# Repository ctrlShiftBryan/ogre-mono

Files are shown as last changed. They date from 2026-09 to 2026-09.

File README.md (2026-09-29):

# Ogre 68

A 68-key ergonomic keyboard, written by hand for
[ergogen](https://ergogen.xyz): key layout, board outline and a KiCad PCB, all
generated from one `ergogen/config.yaml`. It is a wireless split: one PCB per
half, each with its own nRF52840 module and power section on the board, laid
out for JLCPCB assembly.

34 keys a half: four staggered rows, a three-key inner column, a lone Esc
outboard of the number row, two arrow keys, and a four-key thumb cluster fanned
30°. Standard keycap sizes throughout — 1U alphas, 1.5U/1.75U/1.25U on the outer
column, 1.25U and 2.25U thumbs. `ergogen/README.md` describes the design;
`ergogen/ogre-ergo.keycaps.svg` renders it.

## Where it stands

- Layout, outline and PCBs all generate from the config: 68 keys on a 5x7
  matrix per half laid out for routing (the physical columns and rows, with
  the thumbs, arrows and Esc / Del fitted in), hotswap sockets
  with one diode per key, and an Ebyte E73 nRF52840 module with the nice!nano
  v2's power section on each half, all surface mount from JLC's parts library.
- The design's own values — column staggers, thumb fan, half separation — are
  named in the config's `units` block, so the board is tuned in one place.
- `npm run snapshot` holds the geometry against a committed baseline, so a key
  that moves without you meaning it fails.
- `npm run check` passes: wiring, every controller and power pin on its net,
  and KiCad DRC with no violations beyond the unrouted connections.
- **Next:** routing: a routed board as the copper master, with the build syncing
  placement into it. Mounting holes wait on the case.

## Working on it

```sh
cd ergogen && npm install
npm run serve     # live viewer on http://localhost:5174
```

The viewer watches `config.yaml` and `footprints/`, rebuilds on save and
refreshes itself: keycaps, points, outlines and the PCB, with the snapshot and
check scripts a button away. `ergogen/README.md` covers the other commands, the
PCB's matrix and break lines, and the ZMK changes the two removed keys imply.

## The rest of the repo

| Where | What |
|---|---|
| `ergogen/` | The Ogre 68: config, custom footprints, build and check scripts, live viewer |
| `layout/` | The 2019 Ogre Ergo's KLE design, its renderer, and an index of every KLE gist |
| `docs/ogre-repos.md` | Inventory of every Ogre repo — PCBs, firmware branches, tooling — and the project timeline |

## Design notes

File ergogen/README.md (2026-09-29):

# The Ogre 68 in ergogen

`config.yaml` is the whole board, written by hand for
[ergogen](https://ergogen.xyz): key layout, board outline and an unrouted
KiCad PCB. It needs ergogen 4.1+ and the custom footprints in `footprints/`.
On ergogen.xyz (or a local clone of `ergogen/ergogen-gui`), load it from GitHub
with the repo URL (it finds `ergogen/config.yaml` and `ergogen/footprints/`
itself); pasting the YAML alone won't work, because the footprints wouldn't
load. That web UI reads the pushed repo, not the working tree, and its local
file picker is a one-shot upload that brings no footprints; for local work
use `npm run serve` below.

| File | What it is |
|---|---|
| `config.yaml` | Layout, outline and PCB |
| `footprints/` | The switch, its socket and diode, the nRF52840 module, charger, LDO, passives, crystal, connectors, switches, LEDs and SWD pads on the board (`ogre_*.js`); the 2019 PCB-mount switch, diode, Pro Micro and TRRS jack, the nice!nano and the through-hole JST PH connector, available but not placed |
| `footprints/jlc/` | Footprints pulled verbatim from JLCPCB's parts library with easyeda2kicad, one per assembled part, each carrying its LCSC number; `jlc.js` turns them into ergogen footprints |
| `serve.js` | Live viewer: watches the config, rebuilds and shows every view |
| `bundle.js` | Packs the config and footprints into an archive the web UI can open |
| `points.snapshot.json` | Baseline geometry for `npm run snapshot` |
| `ogre-ergo.keycaps.svg` | Key preview |
| `ogre-ergo.keycaps-print.svg` | The same keys for printing: white caps, black type, 1:1 in mm |

## The design

Everything that shapes the board is named in the config's `units` block. The
zones below it place keys and give them legends; the shape lives in `units`.

- **34 keys a half.** Four rows across six columns (outer, pinky, ring, middle,
  index, inner), a three-key extra column inboard of them, a lone Esc on the far
  column, two arrow keys below ring and middle, and four thumb keys.
- **Column stagger.** Each column steps against the one before it, and the
  steps add up to the profile across the hand: the middle column is highest at
  +0.375U, falling away to the pinky on one side and the inner and extra
  columns on the other. `stagger_far` through `stagger_extra`.
- **Key sizes.** 1U throughout, except the outer column's wide caps —
  1.5U Tab, 1.75U Caps Lock, 1.25U Ctrl — right-aligned to the pinky column.
- **Thumb cluster.** Three columns fanned `thumb_splay` (−30°) off the bottom
  of the middle column: 1.25U Cmd, 2.25U Shift, then 1.25U Alt with a 1U Home
  above it. The wide thumb caps are drawn as wide keys turned 90°, so switch
  and stabilizer footprints face the right way.
- **Halves.** Mirrored about an axis `half_spread` (4.25U) right of the extra
  column, which sets the gap between them.

## Legends

Each key has a `legend`: what's printed on a standard keycap set, not the
firmware keymap. `mirror.legend` is the legend of the matching key on the
right half, since ergogen builds the right half by mirroring the left. The PCB
prints each legend on both silkscreens, under its switch (readable from the
back once the switches are in).

Two-part legends are written shifted character first, then base, separated by
a space: `'! 1'` is the key with `!` over `1`. Anything else (`Esc`,
`Caps Lock`, `←`) is a single legend.

## The PCB

Two boards, always split, one per half: `left` and `right`, each its own KiCad
PCB with its own nets. Wireless only, with the controller on the board itself:
an nRF52840 module and the nice!nano v2's power section, all surface mount on
the back, for JLCPCB assembly. The matrix comes from the 2019 Ogre Ergo, where
it was fabricated and worked; the switch footprint from the 2024 rework
(`ogre.2024.pretty`); everything JLC places uses JLC's own footprint
(`footprints/jlc/`), so the pads and orientation match their line.

- **Key numbers.** Each half numbers its keys 1–34 in points order: up each
  column from the outer edge inward, then the thumbs. Key *n* on a half is that
  board's switch MX*n*, socket S*n* and diode D*n*. The keycap render
  (`ogre-ergo.keycaps.svg`, and the viewer's Keycaps tab) prints each key's
  number as L*n* or R*n*, and `npm run check` fails if a part is numbered out
  of step with its key.
- **One 10×7 matrix, one hotswap socket and one diode per key**, COL2ROW. The
  switch (`ogre_hotswap`) is holes, cap outline and legend; its copper is the
  socket (`ogre_socket`, a Kailh-compatible MX socket, JLC's clone) and the
  1N4148W diode in SOD-123F (`ogre_socket_diode`), each a part of its own on
  the back so it can be moved clear of traces. The socket places itself over
  the switch's pins; a key's `diode: [x, y, r]` in the zones places its diode
  (mm from the key, in its frame, y up; `mirror.diode` for the right half),
  and without one it sits at the switch's right edge, where the 2024 footprint
  had it built in. The 2.25U thumb keys add stabilizer holes (a key's `stab`),
  and a key's `turn` would turn its switch and socket together (no key uses it
  now). The grid is laid out for routing, five rows by seven columns:

  |          | col0 | col1 | col2 | col3 | col4 | col5  | col6 |
  |----------|------|------|------|------|------|-------|------|
  | **row0** | + =  | 1    | 2    | 3    | 4    | 5     | ~ \` |
  | **row1** | Tab  | Q    | W    | E    | R    | T     | } ]  |
  | **row2** | Caps | A    | S    | D    | F    | G     | PgDn |
  | **row3** | Ctrl | Z    | X    | C    | V    | B     | Home |
  | **row4** | Esc  |      | ←    | →    | Cmd  | Shift | Alt  |

  Each column net runs down a physical column, col0 the outer column through
  col6 the extra column, and each thumb key joins the column above it. Rows
  0–3 are the physical rows, with Home filling the extra column's empty bottom
  spot, and row4 gathers the rest: Esc, the arrows and the other thumbs. The
  right half is the same grid, mirrored (Del, End, Fn, Enter), on rows 5–9.
  Each half is its own PCB with its own nets, so the numbering across both is
  a convention, not a wire.
- **The controller** (MCU1): an Ebyte E73-2G4M08S1C, an nRF52840 module with
  its antenna, matching and crystals inside, lying sideways on the back below
  the extra column's home key (PgDn / `" '`), where that column has no bottom
  key, with its ceramic antenna end just inside the half's inner edge. Keep
  copper off that end on both layers; the diodes of the two keys beside it are
  moved out of its way in the zones. Its pin map is in `footprints/ogre_e73.js`: the seven
  columns on P1.10 P0.03 P0.28 P1.13 P0.02 P0.29 P0.31 (module pins
  2–9), the half's five rows on P0.30 P0.26 P0.06 P0.05 P0.08 (pins
  10–16; P1.11 on pin 1 and P1.09 on pin 17 are free), and the nice!nano's roles kept on the
  nice!nano's pins, so ZMK's `nice_nano_v2` configuration carries over with
  the matrix pins renamed: P0.13 cuts the LDO (`PWR_EN`), P0.15 drives the
  status LED (`BLED`), P0.18 is reset, battery voltage is read from VDDH.
- **Power, as on the nice!nano v2.** The battery (BAT) goes through the slide
  switch (VBAT) into a TI BQ24075 charger and power path (IC1): USB on IN,
  the battery on BAT, and OUT (VDDH) feeds the module in high-voltage mode,
  from USB when it's plugged in and the battery otherwise. 500 mA from USB
  (EN1 high, EN2 low), charging whenever USB is there (CE low, SYSOFF low),
  charge current set by the 10k on ISET (about 100 mA; a smaller resistor
  raises it), the thermistor faked with 10k on TS. The module's own regulator
  puts 3.3 V out on DCCH, which L1 (10 µH) carries to VDD. A Torex XC6220 LDO
  (IC2) makes VCC from VDDH for anything the board powers besides the module
  (LED strips, one day); its CE is pulled up to VDDH through 10 MΩ and driven
  by P0.13 (`PWR_EN`), so firmware can cut it. A 32.768 kHz crystal (Y1, FC-135)
  with 12 pF caps is the low-frequency clock. Nets and values are checked by
  `npm run check`.
- **USB** comes over a one-to-one 4-pin cable from a Unified Daughterboard S1
  ([unified-daughterboard.github.io](https://unified-daughterboard.github.io/))
  mounted in the case, which carries the USB-C port, its fuse and ESD
  protection. The board's end is a Molex Pico-EZmate (J2, 78171-0004) with the
  daughterboard's pinout, 1 VBUS 2 D− 3 D+ 4 GND, below S (L on the right),
  opening toward the index column.
- **Battery connector** (J2): a JST PH 2-pin side-entry surface-mount connector
  (S2B-PH-SM4-TB) below Q (P on the right), the plug entering from the outer
  edge's side, + on BAT and − on GND. JST sets no polarity. Pad 1 is +, the Adafruit and
  SparkFun convention (the battery plug's mating face toward you, polarizing
  bump up: red on the right), which the community wireless Corne also uses;
  the silkscreen marks it. About half of generic LiPos come wired the other
  way: check a new battery against that picture (or a multimeter) and swap its
  crimps, or set the connector's `plus` to 2.
- **Power switch** (SW2): a Shouhan MSK-12C02 side-actuated SPDT slide switch
  (pin-compatible with the Alps SSSS811101 the community wireless Corne uses),
  on the half's inner edge below `~ \`` (PgUp on the right), lever out past
  it. BAT comes in on the common pin 2, VBAT goes out on pin 1
  when on (the silkscreen marks that end ON), and pin 3 is left open, as on
  the Corne.
- **Reset** (SW1): a 5.1 mm surface-mount tactile switch (TS-1187A) below
  `~ \`` (PgUp on the right), beside that key's diode, wired across its
  diagonal pads so it works whichever way its pin pairs run.
- **SWD** (J3): six bare pads and three locating holes for a Tag-Connect
  TC2030-NL cable, under T / Y. The module arrives blank; this is how the UF2
  bootloader gets on once (any SWD probe; a Raspberry Pi Pico running
  debugprobe will do).
- **LEDs**: two 3 mm through-hole LEDs on the front, soldered by hand, on a tab
  below Esc (Del on the right) so they shine up through a hole in the case
  just below that key, one above the other: LED2 the charge LED (VDDH through
  1k, sinking into the charger's CHG, orange) and, below it, LED1 the status
  LED (P0.15 through 1k, blue). Each stands with its two pads in a line down
  the tab, the flat side (cathode) at the footprint's origin and the anode
  above it, so a bent-over LED shines sideways.
- **Where the rest sits.** Nothing juts out of the outline for the controller:
  the parts hide on the back in the 10 mm strips between one key's socket and
  the next key's switch pins. The module's inductor, capacitors and the crystal
  are in the strip between G and B, next to the module's pad end; the charger
  and LDO with their passives in the strip between `} ]` and PgDn; the SWD
  pads under T, between that switch's side pins; the USB connector below S,
  the battery connector below Q, and reset and the power switch below `~ \``,
  the switch on the inner edge, as placed in KiCad. Each is placed from a nearby key in
  the config (`mcu_x` / `mcu_y` for the module) and the right half reuses the
  same placement from the mirrored key. The config's numbers are a working
  first layout, not a final one: move parts in KiCad and carry them back (see
  `AGENTS.md`).
- **Outline:** keycap edges with 1 mm corners, thumbs included. The thumb
  cluster joins the matrix by filling only the gaps between neighboring keys
  (`thumb_web`), and one pocket per half is cut out over Cmd, as on the 2019
  board. Each half's inner edge runs straight up just inside its inner column,
  and the LED tab (`led_tab_w`, `led_tab_h`) hangs below Esc / Del. The `left`
  and `right` outlines are the halves; `board` is both together, for viewing.
- **No underglow LEDs**, no alternate-size switch footprints, and no mounting
  holes yet (see below).

### Ordering from JLCPCB

Every part JLC places carries its LCSC number as a footprint property
(`LCSC Part`), read from the footprint file in `footprints/jlc/` or set per
part in the config (the passives). The three hand-soldered footprints, the
switch outline, the LEDs and the SWD pads, carry none, and `npm run check`
holds that line. The bill of materials and placement files come out of the
routed board with KiCad's Fabrication Toolkit plugin (or Bouni's
kicad-jlcpcb-tools), which reads that property; the sockets and diodes sit on
the back with everything else, so assembly is single-sided. The module needs
JLC's Standard assembly tier and X-ray inspection. Stock on the module is the
one thing that can hold an order up: buy it into the JLC parts library early.

Both boards sit on KiCad's page at their `pcbs.<half>.params.origin` in the
config: after ergogen runs, `build.js` moves each finished PCB there as a whole
and puts KiCad's drill origin at the same spot. Ergogen's own coordinates (the
points, the snapshot, the reference DXFs) stay where they were.

Routing is left for KiCad. The PCBs are build output, not committed files:
`npm run build` writes `output/pcbs/left.kicad_pcb` and `right.kicad_pcb`, each
with a `.kicad_pro` beside it so KiCad opens it as a project. Every build
rewrites the boards in place (never deleting them, so KiCad can keep one open)
and leaves the project files and KiCad's other files alone; anything done to a
board in KiCad is replaced, so route in a copy. The projects have no schematic;
the board and its nets are the whole design.

The copy is `routing/left.kicad_pcb` (left half only, for now), committed: the
build's board with the parts not yet placed parked off its right edge. Routing
goes one section at a time: `python3 route.py <section>` leaves every pad
outside that section's parts and nets unconnected for the run, locks the
traces already there, runs [Freerouting](https://github.com/freerouting/freerouting)
headless (its jar in `~/.local/share/freerouting/`, or `FREEROUTING` set to
it), brings its traces into the board and reports what's still unrouted and
any DRC errors. The sections are listed in `route.py`; `matrix` is the
switches' columns, rows and diodes. The script also corrects two things
Freerouting gets wrong from KiCad's export: clearance to the curved board
edge, and hole keepouts on the turned thumb keys (see `fix_dsn`).

## Commands

```sh
npm install
npm run build    # write output/ (points, outlines, PCB)
npm run keycaps  # build, then render ogre-ergo.keycaps.svg with legends
npm run keycaps:print  # the same, black on white, as ogre-ergo.keycaps-print.svg
npm run snapshot # fail on geometry that changed since the last baseline
npm run check    # check the generated PCB's parts, nets and KiCad DRC
npm run serve    # live viewer on http://localhost:5174
npm run bundle   # pack config + footprints into output/ogre-ergo.ekb for the web UI
npm run reference # output/reference-left.dxf / -right.dxf, to draw a new outline over
npm run kicad    # build, then open a half's KiCad project (npm run kicad right)
```

`npm run kicad` opens `output/pcbs/left.kicad_pro` in KiCad (`npm run kicad
right` for the other half), to look the board over, run DRC or place parts. Placements made there come back by hand into
`config.yaml` (see `AGENTS.md`); everything else on the board is replaced by the
next build. After a rebuild (`npm run serve` rebuilds on every save), **File >
Revert** in the PCB editor loads the new board.

`npm run reference` plots each built half to a DXF for a vector editor: board
edge on `Edge.Cuts`, keycaps on `User.Drawings`, and the courtyards of the
switches and reset switches on `F.Courtyard`
and `B.Courtyard`. Units are mm and the coordinates are ergogen's own, y up, so
a drawing that keeps them lines up with the config, and the two halves line up
with each other. It needs `kicad-cli`.

`build.js` runs ergogen with the footprints in `footprints/`. The ergogen CLI
only loads custom footprints from a folder, and this folder also holds
`node_modules`.

`npm run keycaps` runs `render_keycaps.py`, which needs Python 3 and PyYAML
(`pip install pyyaml`; on macOS with Homebrew's Python, which refuses a
plain `pip install` and has no `pyyaml` formula, use
`python3 -m pip install --user --break-system-packages pyyaml`). `npm run serve`
renders it too, so without PyYAML the viewer prints `No module named 'yaml'`
on every rebuild. It reads the `output/points/points.yaml` that ergogen
writes in debug mode and draws each key as a keycap with its legend: alphas
in cream, modifiers and arrows in grey, Esc and Enter in red. With `--print`
(`npm run keycaps:print`) every cap is white with black type on a white
page, and the SVG is sized in mm, so it prints at 1:1: 412 × 176 mm, on
tabloid (11 × 17 in) landscape.

`npm run snapshot` is the regression gate. It holds the build against
`points.snapshot.json` — position, rotation and size of all 68 keys — and fails
on any key that moved, appeared or went. A change you meant to make is a new
baseline: `npm run snapshot:update` rewrites the file and prints what it
accepted, and that file goes in the commit with the config change that caused
it.

`npm run serve` starts a viewer that watches `config.yaml` and `footprints/`,
rebuilds on save (about 0.4 s) and refreshes the browser by itself, so the
files in this folder stay the single source of truth. Tabs: **Keycaps** (the
`render_keycaps.py` render), **Points** (ergogen's demo), **Outline** (any
outline in `output/outlines/`) and **PCB** (rendered by `kicad-cli`, with a
layer picker; **edge + keycaps** lays every keycap over the board outline). Drag to pan, wheel to zoom about the pointer, double click (or
**fit**) to fit the pane. The `snapshot` and `check` buttons run those scripts
and print their output. A YAML or footprint error shows in a red bar and the last good
render stays up until the next good build. Nothing leaves the machine.

`npm run bundle` writes `output/ogre-ergo.ekb`, a zip holding `config.yaml`
and `footprints/` as they are in the working tree. The ergogen web UI opens it
under **From Local File**, footprints and all, so the PCB generates there too.
Loading a bare `config.yaml` instead gives the layout and outlines but no PCB,
since the footprints wouldn't come with it. The archive is a snapshot: edits
made in the web editor don't come back to these files, so re-run `npm run
bundle` after changing the config.

`npm run check` reads the generated PCB and fails unless every key has one
switch, one socket and one diode wired column → socket → diode → row, no two
keys share a matrix position, the module's pads carry the nets listed above,
the charger, LDO, crystal, passives, connectors, switches and LEDs are wired
as described, and every assembled part carries its LCSC number. If
`kicad-cli` is installed it also runs KiCad's DRC (overlapping parts, hole and
edge clearances) and fails on any violation other than the unrouted
connections and the switch pins that pass through their sockets' courtyards.

## Firmware notes

With the nRF52840 on the board, ZMK wants a board definition of its own rather
than a shield on `nice_nano_v2`. Start from ZMK's `nice_nano_v2` board files
(the same charger, regulator cut-off on P0.13, battery read from VDDH, status
LED on P0.15, external 32 kHz crystal). The matrix no longer matches the ZMK
`ogre_ergo` shield in `ctrlShiftBryan/zmk-config2` (`boards/shields/ogre_ergo/`)
or QMK's `ogre/ergo_split`: both are 5×7 too, but with the keys in
different spots.

- **kscan per half:** five rows on P0.30 P0.26 P0.06 P0.05 P0.08 and
  seven columns on P1.10 P0.03 P0.28 P1.13 P0.02 P0.29 P0.31, COL2ROW,
  so `diode-direction = "col2row"`.
- **Transform:** 5 rows × 14 columns, `col-offset = <7>` for the right half,
  the grid in the PCB section above: Esc (Del) is RC(4,0), the arrows
  RC(4,2) and RC(4,3), Cmd, Shift and Alt RC(4,4)–RC(4,6), Home (End)
  RC(3,6). 68 entries, in the same key order as the keycap render.
- **Bindings** carry over key by key; only their `RC` positions change.

## Not done yet

- **Mounting holes.** None yet. They sit at key corners, so they follow from
  the case, and the case is a new design too.
- **Routing**, in KiCad.

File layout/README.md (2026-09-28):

# Layouts

`ogre-ergo.kle.json` is the 70-key Ogre Ergo of 2019, the board that came
before the Ogre 68. `ogre-ergo.svg` is its render, `kle.py` the renderer, and
`kle-gists.md` indexes every KLE gist on the account.

## The original KLE designs (gists)

The Ogre was designed in keyboard-layout-editor.com, which saves layouts as
GitHub gists. The account holds about 150 keyboard gists from 2019-04 to
2025-09; `kle-gists.md` indexes all of them with key counts. The ones
that matter, verified against the QMK readme photos and the KiCad footprints:

Only the 2019 board is copied locally; the rest live in their gists.

| Gist | Date | What it is | Copy in `layout/` |
|---|---|---|---|
| [ogre - proto 2 - right](https://gist.github.com/ctrlShiftBryan/c3e7732efbd659caf811a79142388f24) | 2019-06-12 | **The 70-key Ogre Ergo as built.** Mirrored thumb clusters of 1.25u (rotated 30°) + 1×2.25u + 1×1.5u; 1.5/1.75/2.25u row ends. Matches the split photo in the QMK readme. | `ogre-ergo.kle.json` |
| [ogre-starter](https://gist.github.com/ctrlShiftBryan/92e689435b2e871f4e3be34ff3fdfdd7) | 2020-01-25 | Same board dressed with 1u/1.5u/2u caps (two days before the QMK PR). | — |
| [Ogre-ergO tkl](https://gist.github.com/ctrlShiftBryan/371187f112595510258a5386cc92757c) | 2019-07-01 | The 68-key first PCB in the `ogre` repo (2.75u/2u thumb keys; footprint counts match). QMK branch `ogre-v2`. | — |
| [OGRE 2025](https://gist.github.com/ctrlShiftBryan/924e0f9423bcae3f99e5aeea24a7db68) | 2025-09-01 | New 62-key design, uniform 1u with 1×1.5u thumbs. | — |

Each `.kle.json` has a matching `.svg` render. `layout/kle.py` is a small
deserializer that follows KLE's own rules (the npm `kle-serial` build mishandles
`rx`/`ry` cluster resets) and renders the SVGs.

**The QMK geometry is not the design.** Bryan's PR-era `info.json` files were
empty; the `keyboards/ogre/ergo_*` coordinates in upstream QMK were added by a
maintainer in June 2020 (#9549) with no rotation and guessed thumb heights. Read
them as a matrix, never as a layout: the ZMK `ogre_ergo.dtsi` transform in
zmk-config2 lists the same 70 keys in the same order (RC(row,col) is the
transpose of QMK's [row,col]), and `ergogen/README.md` maps the redesign onto
it.

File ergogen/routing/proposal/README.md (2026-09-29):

# Left-half placement proposal

Not yet the design: `config.yaml` still places the parts as before. This is a
proposal to review in KiCad before it's carried into the config.

- `left-placed.kicad_pcb`: every part placed, unrouted. The module's matrix
  pins are reassigned onto its outer-row pads (col0-col6 on 10 9 7 6 4 3 1,
  row0 17, row1 35, row2 15, row3 8, row4 2), J1 sits under Q and J2 under A
  with their plugs entering sideways, and the support parts cluster at their
  pins around the module.
- `left-trial.kicad_pcb`: the same board autorouted in one throwaway pass
  (every net but GND): 0 unrouted, 93 vias, 1 DRC nit. A check that the
  placement routes, not routing to keep.
- `place.py` made the placement from the build's board (greedy, each part at
  the free spot nearest what it connects to); `trial.py` made the trial route.

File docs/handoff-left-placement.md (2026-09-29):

# Handoff: left-half placement, then routing by section

Written 2026-09-29 at the end of a session. The next session carries the
reviewed placement proposal into `ergogen/config.yaml`, then routes the left
half one section at a time. Read `AGENTS.md` and `ergogen/README.md` (the
"Routing is left for KiCad" paragraph onward) first; this doc covers only
what isn't written down there.

## Where things stand

- The matrix is 5x7 per half (`4b5570b`), drawn as a table in
  `ergogen/README.md`.
- `ergogen/routing/left.kicad_pcb` is the routed board, committed and the
  master for copper (`bfaa034`, AGENTS.md). It currently holds **no traces**
  (the first matrix autoroute was ripped, `de26bb1`) and the **old placement**,
  with the support parts parked off the right edge.
- `ergogen/route.py` autoroutes a named section (`python3 route.py <section>`)
  and rips one (`python3 route.py rip [section]`). Only `matrix` is defined so
  far. Its docstrings explain the DSN fixes.
- **The placement proposal to carry into the config** is in
  `ergogen/routing/proposal/` (`10f01cf`; see its `README.md`). The user was
  about to review it in KiCad on another machine. If they moved parts there,
  their committed board is the source to encode, not `left-placed.kicad_pcb`
  as generated. Pull first.

## Decisions made with the user

- Workflow: place every part first, then route by section, most constrained
  first. Order: module support parts (crystal, supply caps, L1), power
  (battery, switch, charger, LDO), USB, reset/SWD/LEDs, matrix to module,
  matrix. Ground pour last. Commit each section on its own; the user reviews
  between sections.
- Freerouting gets no layer bias.
- J1 (USB cable to the daughterboard, which sits just above the 3 key) goes
  under Q. J2 (battery, under the board) goes under A. **Both plugs enter
  sideways**, along the band below the key, or they hit the hotswap socket
  underneath. Their bodies lie horizontally in that band.
- Fixed in place: the power switch SW2 (lever out the inner edge) and the LEDs
  on the tab. Everything else can move.
- The module stays in its spot below PgDn with its antenna at the inner edge;
  only its offset can change.

## The proposal's matrix pin map (not yet in the code)

Every matrix net on an outer-row pad. The inner row (12, 14, 16, ...) can't be
reached without a via under the module.

| net  | pad | GPIO  | | net  | pad | GPIO  |
|---|-----|---|---|---|-----|---|
| col0 | 10  | P0.30 | | row0 | 17  | P1.09 |
| col1 | 9 | P0.31 | | row1 | 35  | P0.24 |
| col2 | 7 | P0.02 | | row2 | 15  | P0.05 |
| col3 | 6 | P1.13 | | row3 | 8 | P0.29 |
| col4 | 4 | P0.28 | | row4 | 2 | P1.10 |
| col5 | 3 | P0.03 | | | | |
| col6 | 1 | P1.11 | | | | |

P0.15 (LED, pad 28, inner row) keeps its pad for nice!nano compatibility and
needs one via under the module. Pads 12, 14 and 16 (P0.26, P0.06, P0.08) come
free.

## Next steps

1. Pull, and ask whether the user changed the proposal in KiCad.
2. Encode the placement in `config.yaml`: each part as a `where` shift from a
   nearby key, in the key's frame with y up (AGENTS.md, "Placing parts in
   KiCad"). D34's new spot goes in the zones as `thumb.far.rows.upper.diode`.
   The right half reuses the shifts mirrored; check that the right board comes
   out sensible too, since only the left was ever looked at.
3. Update the pin map in `footprints/ogre_e73.js` (`PADS`), `check-pcb.js`
   (`expectedMcu`'s pad lists) and `ergogen/README.md` (controller paragraph
   and firmware notes' kscan pins).
4. Add an antenna keepout (rule area: no tracks, vias or pours, both layers)
   to `ogre_e73.js`. `routing/proposal/trial.py` adds a temporary one from
   1 mm past pad 1 to the board edge, module ±3 mm.
5. `npm run build`, `snapshot`, `check`. Copy the build's left board (and
   `.kicad_pro`) over `routing/left.kicad_pcb`; it has no traces yet, so a plain
   copy is safe. Commit.
6. Add the sections to `route.py`'s `SECTIONS` and route them in the order
   above, one per turn with the user reviewing in KiCad (File > Revert to
   reload).

Open review points the user hasn't answered yet: the supply caps sit 4–6 mm
from the module's power pads (the row channel and B's socket crowd that end);
col6 on pad 1 runs beside the antenna keepout; the LED resistors sit by the
module, so the LED lines cross the whole board.

## Gotchas

- KiCad 10's Python bindings: iterating `board.Tracks()` fails (index it,
  as `route.tracks()` does), and removing footprints from Python corrupts the
  SWIG proxies. Every pcbnew run prints `property.h` asserts: noise.
- Freerouting (2.4.1) misplaces keepouts on footprints turned off a right
  angle and crowds curved edges; `route.py`'s `fix_dsn` corrects both. It
  also necks traces below the 0.2 mm minimum now and then; `route.py` widens
  them back.
- Freerouting on a new machine: `gh release download v2.4.1 --repo
  freerouting/freerouting --pattern 'freerouting-2.4.1.jar'` into
  `~/.local/share/freerouting/` (or set `FREEROUTING`). Java 21 or newer.
- `npm run serve`'s watcher and every build rewrite `output/pcbs/*`; never
  work there.
- DRC's `npth_inside_courtyard` and `lib_footprint_issues` are the design's own
  (`route.py`'s `EXPECTED`).

## Working with this user

- Ask questions **one at a time**, the most blocking first, with a
  recommended default.
- Commit each change as it's made, straight to `main`; push when asked (they
  switch machines, and `origin` may have commits from the other one: rebase).

## Suggested skills

- `writing-for-agents` before editing `AGENTS.md` (the routing workflow line
  may need a sentence once sections exist).
- `diagnosing-bugs` if Freerouting or the KiCad bindings misbehave in a new way.
- `code-review` over the session's commits (`4b5570b..10f01cf`) before
  building further on `route.py`, if wanted.

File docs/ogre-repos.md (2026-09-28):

# Ogre repos, an inventory

Every GitHub repo under `ctrlShiftBryan` that belongs to the Ogre keyboard
project (the Ogre Ergo and its siblings), plus the tooling and firmware repos
that orbit it. Surveyed 2026-09-12 from the GitHub API and fresh clones.

**What the Ogre is.** The Ogre Ergo is an ErgoDox-inspired, "keycap friendly"
70-key ergonomic board designed in KiCad by Bryan Arendt (ctrlshiftba) in
2019. It uses Pro Micro controllers, MX/Alps hybrid hotswap footprints, and
14 WS2812B underglow LEDs. It ships in QMK upstream as `ogre/ergo_split` and
`ogre/ergo_single` (same PCB, merged Jan 2020, PRs #8011 and #8012). The
Jabberwocky is a second Ogre-branded PCB from late 2019. In 2024-2025 the Ergo
was reworked around a nice!nano v2 and ZMK. The current work is the Ogre 68 —
see the top-level README.

## Core repos (the Ogre itself)

| Repo | Vis. | Active | What it is |
|---|---|---|---|
| [ogre](https://github.com/ctrlShiftBryan/ogre) | public | 2019-06 → 2019-07 | **First Ogre PCB.** KiCad 5 project (`ogre/ogre.kicad_pcb`, `.sch`), plate SVGs, gerbers in `plots/` and `the.gerber/`. Submodules: Keebio-Parts, keebio-components, ai03 MX_Alps_Hybrid, random-keyboard-parts. 21 commits, from "initial empty project" to "done". |
| [ogre-v1](https://github.com/ctrlShiftBryan/ogre-v1) | private | 2019-10-26 | **Empty KiCad scaffold**, 4 commits in one day (empty project, submodules, fp/sym tables). Superseded the same day by ogre-jabberwocky, which starts from these exact commits. |
| [ogre-jabberwocky](https://github.com/ctrlShiftBryan/ogre-jabberwocky) | private | 2019-10 → 2020-05 | **Jabberwocky PCB.** Full KiCad project (`ogre-v1.kicad_pcb`), routed and marked "final" Nov–Dec 2019. Also holds the Illustrator source for the edge/case cuts (`edge-v2.ai`, `jabberwocky.ai`, `illustrator-cuts/`), DXF exports, silkscreen BMP art (ogre logos, "twas", legends), laser cut file, and gerbers in `plots/`. 42 commits. |
| [ogre.pretty](https://github.com/ctrlShiftBryan/ogre.pretty) | public | 2019-11 → 2021-07 | **KiCad footprint library** (124 `.kicad_mod`). Everything custom for the Ogre: hotswap MX footprints 1u–2.75u incl. reversed-stabilizer and "Salvage" variants, Ogre Ergo edge/outline/plate/cuts by date (12-14, 12-18, 12-19, 12-29, 2020-01-04), silkscreen legends and logos, Jabberwocky legends/holes/edge, Pro Micro Mill-Max, nRF52840 (holyiot 18010, E73), SSD1306 OLED, EC11 encoder, WS2812B. `illustrator/mx-cutout.ai`. |
| [ogre.2024.pretty](https://github.com/ctrlShiftBryan/ogre.2024.pretty) | private | 2024-11 → 2025-05 | **KiCad 8 footprint library for the 2024 rework** (`Library.pretty/`, 8 footprints): CherryMX hotswap (1u, 1.5u, hybrid, with diode), D3 SMD v2 diode, ProMicro v3, JST PH 3-pin battery connector, Kailh Choc V2. |
| [ogre-case](https://github.com/ctrlShiftBryan/ogre-case) | private | 2026-09-11 | **Illustrator case design** for the Ogre Ergo, archived from a USB stick (the only copy). `ogre-ergo-case.ai.xz` (original dated 2022-10-07, 14 MB, xz'd to 5.5 MB) plus `preview.png` outline. README has restore steps and SHA-256. |
| [gatsby-ogre](https://github.com/ctrlShiftBryan/gatsby-ogre) | private | 2020-11-18 → 19 | **Unfinished product site / build guide.** Gatsby + Tailwind + TSX. Pages: index ("ogre ergo"), Ergo, GroupBuy, BuildGuide with 16 step components (Inventory, Diodes, Mill-Max, Pro-Micro, LED, TRRS, Reset Toggle, MX Switches, Remove film, Shield, Mid, Bottom, Top, QMK Flash, Done). Skeleton only, no copy. |
| [crkbd-ogre](https://github.com/ctrlShiftBryan/crkbd-ogre) | public | 2024-11-15 | **Fork of foostan/crkbd** (Corne) via Nick Meyer's `corne-ice` / `cho-corne-ice` wireless variants. One Bryan commit, "start changes", rewrites `corne-ice/pcb/corne-ice.kicad_pcb` (+48k lines) plus a BOM csv. Looks like the starting point for the nice!nano-based Ogre 2024 rework. Submodules: foostan/kbd, bstiq/nice-nano-kicad, cyril279/keyboards. |

## Firmware

| Repo / branch | Vis. | Active | What it is |
|---|---|---|---|
| [qmk_firmware](https://github.com/ctrlShiftBryan/qmk_firmware) (fork) | public | 2019 → today | Upstream QMK carries `keyboards/ogre/ergo_split` and `ergo_single` from Bryan's PRs. The fork's `master` is frozen at 2020-01-27 (18k commits behind). Ogre history lives on branches, listed below. Local clone: `~/code2/qmk_firmware` (checked out on `bryan/altair-keymap`, which is current upstream + personal Altair work). |
| ↳ `ogre-v2` | | 2019-06 → 10 | Earliest QMK keyboard for the Ogre (`keyboards/ogre`, single-board). "ogre v2 works" 2019-07-16. |
| ↳ `ogre72` | | 2019-10 | Adds `keyboards/ogre72`, a 72-key variant with 7u spacebar. Template readme, never upstreamed. |
| ↳ `ogre`, `ogre-split`, `old-master` | | 2019-11 → 2020-01 | Split-keyboard rewrite of `keyboards/ogre` ("create new", underglow, mod-taps). `ogre-split` is the last WIP before the upstream PR. |
| ↳ `ogre-ergo`, `ogre-ergo-single` | | 2020-01 | The exact branches behind upstream PRs #8011 (split) and #8012 (single). |
| ↳ `ogre-changes` | | 2020-03 → 2021-02 | Post-merge personal changes to both ergo keymaps (media keys, layer 2 keys, no split-hand pin, "update non-split"). Most recent Ogre QMK work. |
| ↳ `ctrlshiftba`, `ba-baur` | | 2020-01 → 05 | Personal keymaps for ergo_split. `ba-baur` is "ba bauer v2 keymap" with one-shot layers. |
| ↳ `ogre-jabberwocky`, `ba-jabber-keymap` | | 2019-11 → 12 | `keyboards/ogre/jabberwocky` QMK port and Bryan's keymap. Never upstreamed. |
| [zmk](https://github.com/ctrlShiftBryan/zmk) (fork), branch `ogre-ergo` | public | 2021-03 → 2022-02 | First ZMK port: `app/boards/shields/ogre_ergo/` (dtsi, left/right overlays, keymap, Kconfig, README). 12 commits ahead of a 2021 main. |
| [zmk-config2](https://github.com/ctrlShiftBryan/zmk-config2) | public | 2024-11 → 2025-10 | **Current ZMK user config.** Started for a Corne (nice!nano v2, nice!view, ZMK Studio) in Nov 2024; on 2025-05-26 adds the `ogre_ergo` shield (copied from the zmk fork) and on 2025-05-29 migrates the Corne keymap onto it with hold-tap behaviours and sym/num/nav/settings layers. `build.yaml` builds corne_left/right and ogre_ergo_left/right for nice_nano_v2. Also holds `keymap.afdesign` / `keymap-abbre-img.afdesign` (Affinity keymap diagrams). |
| [zmk-config](https://github.com/ctrlShiftBryan/zmk-config) | private | 2021-03 | Two-commit ZMK user config for a **Kyria** on nice!nano. Not Ogre; contemporaneous with the zmk fork's ogre-ergo branch. |
| [lily58-wireless-zmk-config](https://github.com/ctrlShiftBryan/lily58-wireless-zmk-config) | private | 2023-07 → 2025-10 | ZMK config for a Lily58 (nice!nano v2, ZMK v0.3, Studio). Not Ogre, but the keymap shares the same layer scheme. Has a CLAUDE.md. |
| [keyboard-hex](https://github.com/ctrlShiftBryan/keyboard-hex) | public | 2019-02 | Empty (README only, "my hex files"). |

## Layout / PCB tooling

| Repo | Vis. | Active | What it is |
|---|---|---|---|
| [visual-keyboard-studio](https://github.com/ctrlShiftBryan/visual-keyboard-studio) | public | 2019-05 | Vue + TypeScript app ("keebstudio"): parses a keyboard-layout-editor row/key model, renders keycaps, colour picker per key. 17 commits, deployed to an S3 bucket (see `notes.md`). Predates the Ogre PCB by a month. |
| [kicad-footprint-aligner](https://github.com/ctrlShiftBryan/kicad-footprint-aligner) | public | 2019-07-04 | Vue app, 3 commits, "calculates adjustment" for centring footprints. Written mid-Ogre-PCB routing. |
| [kicad-keyboard-editor](https://github.com/ctrlShiftBryan/kicad-keyboard-editor) | public | 2021-04-13 | VS Code extension scaffold with a `common/parser.ts` for `.kicad_pcb` files (stub file: Voyager60 PCB). 2 commits, hello-world stage. |
| [kle-serial](https://github.com/ctrlShiftBryan/kle-serial) (fork of ijprest) | public | 2019-09 | Unmodified fork of the keyboard-layout-editor.com serialisation library. |
| Forks: [crkbd](https://github.com/ctrlShiftBryan/crkbd), [Voyager60](https://github.com/ctrlShiftBryan/Voyager60), [plain60-c](https://github.com/ctrlShiftBryan/plain60-c), [gh60](https://github.com/ctrlShiftBryan/gh60), [CherryMX](https://github.com/ctrlShiftBryan/CherryMX) | public | 2019–2024 | Reference PCBs and keycap models pulled in while designing. No Bryan commits. |

Not keyboard-related despite the name: `keyboard-maestro` (a macOS Keyboard
Maestro macro export), `Overlook` (KVM client, "full keyboard grab").

## Timeline

| When | Milestone | Where |
|---|---|---|
| 2019-05 | visual-keyboard-studio: KLE-style renderer | visual-keyboard-studio |
| 2019-06/07 | First Ogre PCB designed and routed in KiCad; QMK `ogre-v2` works | ogre, qmk `ogre-v2` |
| 2019-10 | ogre72 variant; ogre-v1 scaffold → Jabberwocky | qmk `ogre72`, ogre-v1, ogre-jabberwocky |
| 2019-11/12 | Jabberwocky routed and finalised; footprint lib started; split QMK rewrite | ogre-jabberwocky, ogre.pretty, qmk `ogre-split` |
| 2020-01 | Ogre Ergo split + single merged into upstream QMK (#8011, #8012) | qmk `ogre-ergo*` |
| 2020-03 → 2021-02 | Personal keymap iterations | qmk `ogre-changes`, `ba-baur`, `ctrlshiftba` |
| 2020-11 | Build-guide website skeleton | gatsby-ogre |
| 2021-03 → 2022-02 | First ZMK shield for Ogre Ergo | zmk fork `ogre-ergo` |
| 2021-07 | Last footprint-library update (hotswap, salvage footprints) | ogre.pretty |
| 2022-10 | Illustrator case design (file date) | ogre-case |
| 2024-11 | New footprint lib; Corne-ice fork as base for wireless rework; ZMK config for Corne | ogre.2024.pretty, crkbd-ogre, zmk-config2 |
| 2025-05 | Ogre Ergo shield added to zmk-config2, keymap migrated from Corne | zmk-config2 |
| 2025-10 | Last keymap tweak ("update brackets") | zmk-config2 |
| 2026-09-11 | Case .ai archived from USB drive | ogre-case |

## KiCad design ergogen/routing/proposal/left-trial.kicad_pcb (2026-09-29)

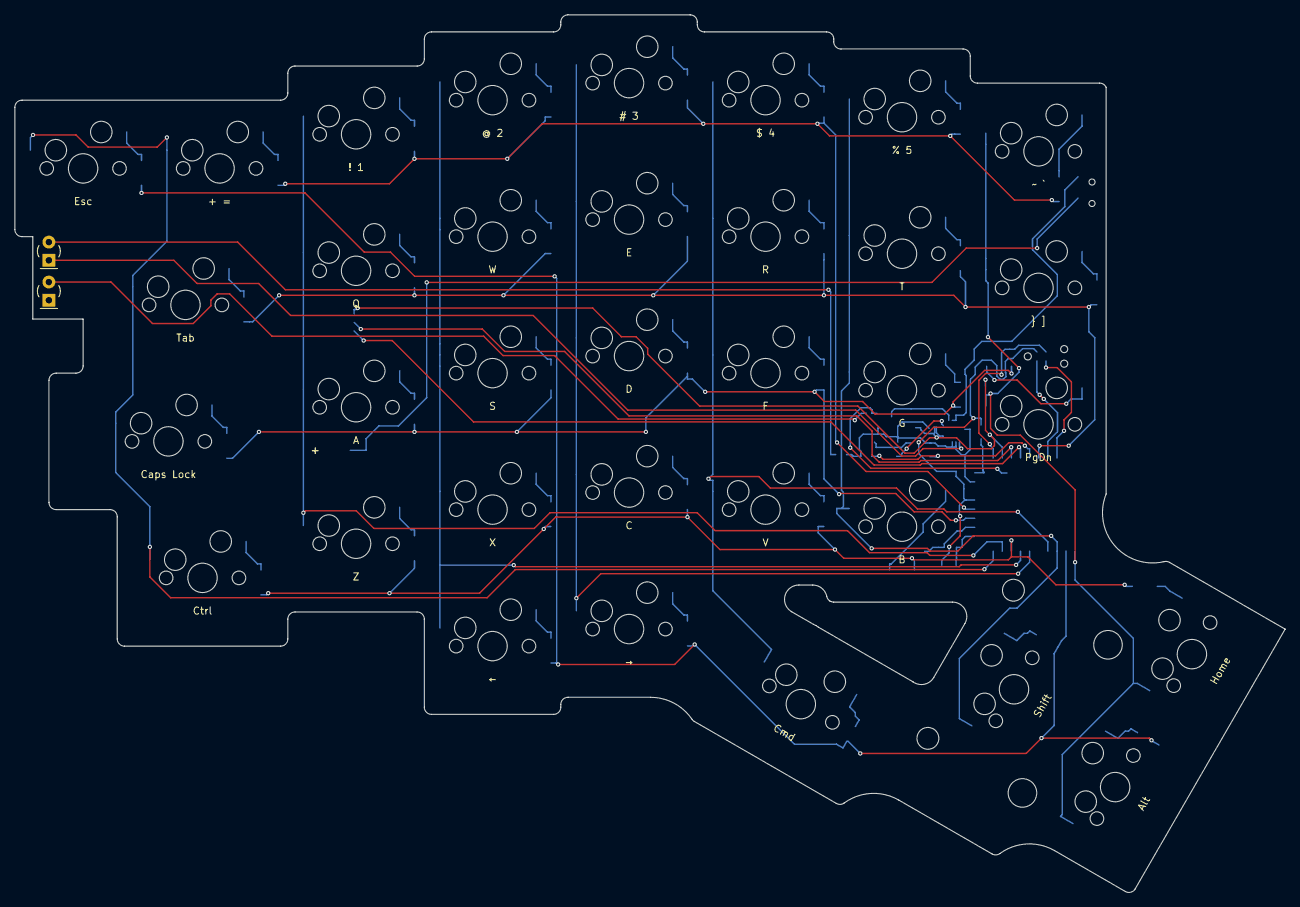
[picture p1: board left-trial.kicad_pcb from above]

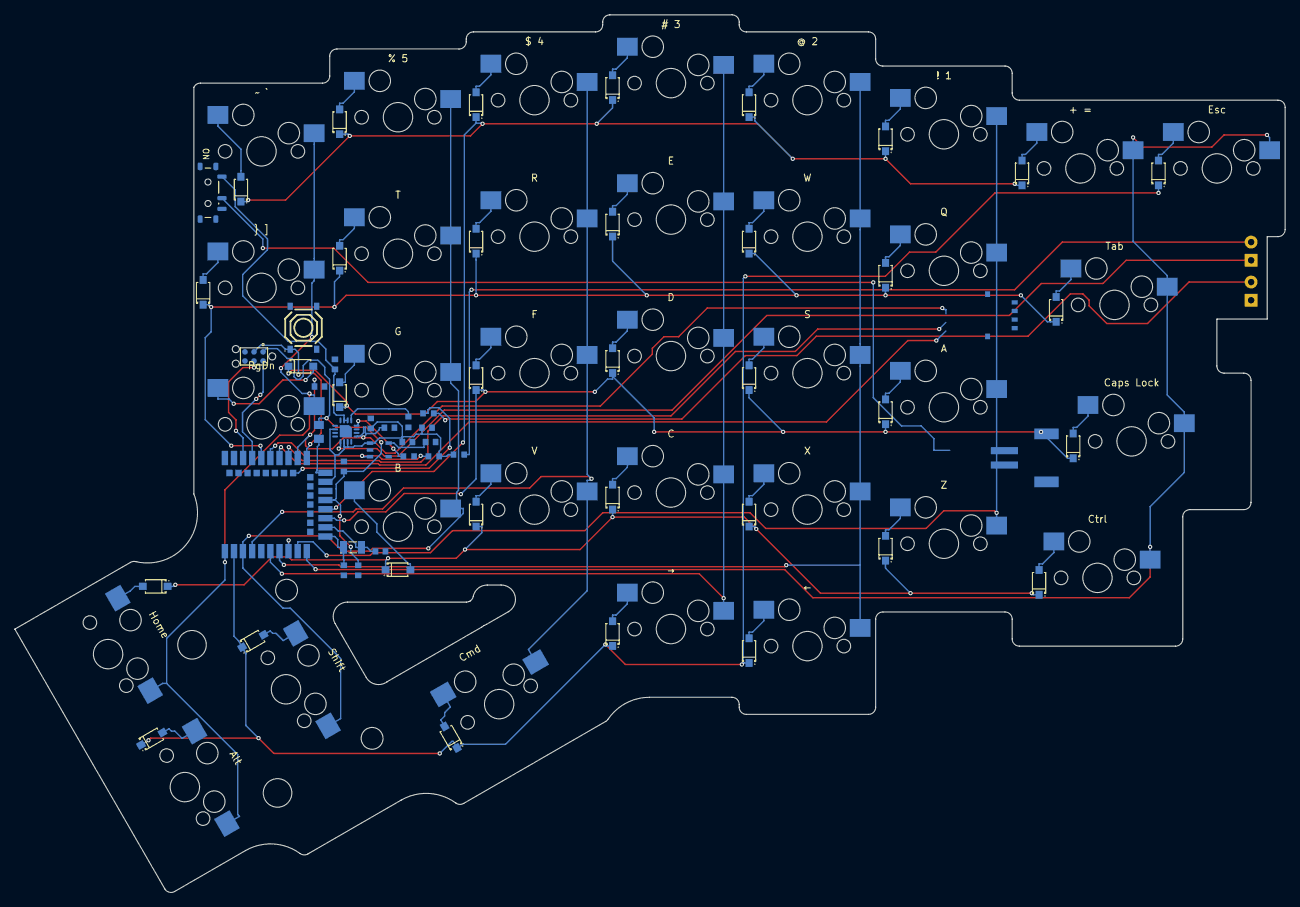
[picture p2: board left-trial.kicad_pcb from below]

Board: 2 copper layers, 177.3 x 122.5 mm, 130 parts (94 on the bottom side), 68 nets.

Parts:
C1, C3, C4, C8, C9, C11: 4.7uF; C_0603
C2: 100nF; C_0603
C5, C6: 12pF; C_0603
C7: 1uF; C_0603
C10: 10uF; C_0603
D1, D2, D3, D4, D5, D6, D7, D8, D9, D10, D11, D12, D13, D14, D15, D16, D17, D18, D19, D20, D21, D22, D23, D24, D25, D26, D27, D28, D29, D30, D31, D32, D33, D34: 1N4148W; Socket_Diode
IC1: BQ24075RGTR; BQ24075
IC2: XC6220B331MR-G; XC6220
J1: USB; USB_PicoEZmate
J2: BAT; JST_PH_S2B-PH-SM4
J3: SWD; SWD_TC2030-NL
L1: 10uH; L_0805
LED1: STATUS; LED_3mm
LED2: CHARGE; LED_3mm
MCU1: E73-2G4M08S1C
MX1, MX2, MX3, MX4, MX5, MX6, MX7, MX8, MX9, MX10, MX11, MX12, MX13, MX14, MX15, MX16, MX17, MX18, MX19, MX20, MX21, MX22, MX23, MX24, MX25, MX26, MX27, MX28, MX29, MX30, MX31, MX32, MX33, MX34: CherryMX_Hotswap
R1, R2: 1k; R_0603
R3, R4: 10k; R_0603
R5: 10M; R_0603
S1, S2, S3, S4, S5, S6, S7, S8, S9, S10, S11, S12, S13, S14, S15, S16, S17, S18, S19, S20, S21, S22, S23, S24, S25, S26, S27, S28, S29, S30, S31, S32, S33, S34: CPG151101S11; Hotswap_Socket
SW1: RESET; SW_Reset_TS1187A
SW2: POWER; SW_SPDT_MSK12C02
Y1: 32.768kHz; Crystal_FC-135

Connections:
BAT: J2.1, SW2.2
BLED: MCU1.28, R1.1
CHG: IC1.9, LED2.1
D+: J1.3, MCU1.31
D-: J1.2, MCU1.29
DCCH: L1.1, MCU1.25
GND: C1.2, C2.2, C3.2, C4.2, C5.2, C6.2, C7.2, C8.2, C9.2, C10.2, C11.2, IC1.4, IC1.5, IC1.8, IC1.15, IC1.17, IC2.2, J1.4, J1.6, J1.7, J2.2, J3.5, LED1.1, MCU1.5, MCU1.21, MCU1.24, R3.2, R4.2, SW1.4
ISET: IC1.16, R4.1
LED_C: LED2.2, R2.2
LED_S: LED1.2, R1.2
PWR_EN: IC2.3, MCU1.33, R5.2
RESET: J3.3, MCU1.26, SW1.1
SWDCLK: J3.4, MCU1.39
SWDIO: J3.2, MCU1.37
TS: IC1.1, R3.1
VBAT: C9.1, IC1.2, IC1.3, SW2.1
VBUS: C4.1, C7.1, IC1.13, J1.1, MCU1.27
VCC: C11.1, IC2.5
VDD: C1.1, C2.1, J3.1, L1.2, MCU1.19
VDDH: C3.1, C8.1, C10.1, IC1.6, IC1.10, IC1.11, IC2.1, MCU1.23, R2.1, R5.1
XL1: C5.1, MCU1.11, Y1.1
XL2: C6.1, MCU1.13, Y1.2
col0: MCU1.10, S1.1, S2.1, S3.1, S4.1, S5.1
col1: MCU1.9, S6.1, S7.1, S8.1, S9.1
col2: MCU1.7, S10.1, S11.1, S12.1, S13.1, S14.1
col3: MCU1.6, S15.1, S16.1, S17.1, S18.1, S19.1
col4: MCU1.4, S20.1, S21.1, S22.1, S23.1, S31.1
col5: MCU1.3, S24.1, S25.1, S26.1, S27.1, S32.1
col6: MCU1.1, S28.1, S29.1, S30.1, S33.1, S34.1
matrix_extra_home: D28.2, S28.2
matrix_extra_num: D30.2, S30.2
matrix_extra_top: D29.2, S29.2
matrix_far_num: D1.2, S1.2
matrix_index_bottom: D20.2, S20.2
matrix_index_home: D21.2, S21.2
matrix_index_num: D23.2, S23.2
matrix_index_top: D22.2, S22.2
matrix_inner_bottom: D24.2, S24.2
matrix_inner_home: D25.2, S25.2
matrix_inner_num: D27.2, S27.2
matrix_inner_top: D26.2, S26.2
matrix_middle_bottom: D16.2, S16.2
matrix_middle_home: D17.2, S17.2
matrix_middle_mod: D15.2, S15.2
matrix_middle_num: D19.2, S19.2
matrix_middle_top: D18.2, S18.2
matrix_outer_bottom: D2.2, S2.2
matrix_outer_home: D3.2, S3.2
matrix_outer_num: D5.2, S5.2
matrix_outer_top: D4.2, S4.2
matrix_pinky_bottom: D6.2, S6.2
matrix_pinky_home: D7.2, S7.2
matrix_pinky_num: D9.2, S9.2
matrix_pinky_top: D8.2, S8.2
matrix_ring_bottom: D11.2, S11.2
matrix_ring_home: D12.2, S12.2
matrix_ring_mod: D10.2, S10.2
matrix_ring_num: D14.2, S14.2
matrix_ring_top: D13.2, S13.2
row0: D5.1, D9.1, D14.1, D19.1, D23.1, D27.1, D30.1, MCU1.17
row1: D4.1, D8.1, D13.1, D18.1, D22.1, D26.1, D29.1, MCU1.35
row2: D3.1, D7.1, D12.1, D17.1, D21.1, D25.1, D28.1, MCU1.15
row3: D2.1, D6.1, D11.1, D16.1, D20.1, D24.1, D34.1, MCU1.8
row4: D1.1, D10.1, D15.1, D31.1, D32.1, D33.1, MCU1.2
thumb_far_cluster: D33.2, S33.2
thumb_far_upper: D34.2, S34.2
thumb_home_cluster: D32.2, S32.2
thumb_near_cluster: D31.2, S31.2

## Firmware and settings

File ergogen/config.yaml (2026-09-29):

# The Ogre 68: a 68-key ergonomic keyboard for ergogen 4.1+.
# `units` below holds the design — column staggers, the thumb fan, the half
# separation. Change the board there; the zones place keys and name legends.
# Below the points: board outline and PCB (custom footprints in footprints/;
# build with `npm run build`, check with `npm run check`, and `npm run snapshot`
# fails on geometry that moved without being meant to).
# Ergogen y points up; KLE/KiCad y points down.
meta:
  engine: 4.1.0
  name: ogre-ergo

units:
  # MX spacing: 19.05 mm pitch, caps 1 mm smaller than the pitch.
  $default_spread: U
  $default_padding: U
  $default_width: U-1
  $default_height: U-1

  # ---- The design ----------------------------------------------------------
  # Every number below shapes the Ogre 68. Change one here, not in the zones,
  # and watch it in `npm run serve`.

  # Column stagger. Each value moves its column against the column before it,
  # so together they draw the profile across the hand. Running total, in U,
  # from the far column: far -0.25, outer -0.25, pinky 0, ring +0.25,
  # middle +0.375, index +0.25, inner +0.125, extra -0.125. The peak is the
  # middle column, the longest finger; the profile falls away on both sides.
  stagger_far: -0.25U      # Esc column, a step below the pinky
  stagger_pinky: 0.25U     # back up from the far and outer columns
  stagger_ring: 0.25U      # ring reaches higher than the pinky
  stagger_middle: 0.125U   # the top of the profile
  stagger_index: -0.125U   # index sits lower than middle
  stagger_inner: -0.125U   # the stretch column, lower again
  stagger_extra: -0.25U    # inner 1u column, lowest of the matrix

  # Thumb cluster: a fan of three columns hung off the bottom of the middle
  # column. The offsets place its near corner, the splay turns the whole fan.
  thumb_offset_x: 23.98
  thumb_offset_y: -10.48
  thumb_splay: -30         # degrees the cluster fans away from the matrix
  thumb_spread: 24.73      # centre to centre, the 1.25u Cmd to the 2.25u Shift
  thumb_stagger_home: 0.875U   # Shift/Alt/Home block, up from Cmd
  thumb_stagger_far: -0.25U    # Alt/Home column, up again from Shift
  thumb_upper_pitch: 1.125U    # Alt to the 1u Home above it

  # Half separation. The mirror axis sits this far right of the extra column,
  # so the gap between the two halves is a result of this number.
  half_spread: 4.25U

  # Controller: the nRF52840 module lies sideways on the back below the extra
  # column's home key (PgDn / " '), where the column has no bottom key, with its
  # antenna end just inside the half's inner edge; the power parts sit in the
  # strips between socket rows in the inner and extra columns. Nothing juts out
  # of the outline for them. `mcu_x` / `mcu_y` are the module's origin from that
  # home key; the origin is 7 mm from its pad end and 11 mm from its antenna end.
  mcu_x: -1.9            # 9.44 (the inner edge) - 0.34 - 11: on the right half the socket of N sits closer, and this clears its pad
  mcu_y: -11.2

  # LED tab: a lip below Esc (Del on the right) for the two 3 mm LEDs, one above the
  # other, which shine up through a hole in the case just below that key. Its right
  # edge runs into Tab's cap, so the two join.
  led_tab_w: 7.5
  led_tab_h: 12.5

  # Outline. The thumb cluster joins the matrix by filling the gaps between
  # keys up to twice this wide; the rest of the edge follows the keycaps.
  thumb_web: 7
  pocket_wall: 1           # board left around each key where a pocket is cut
  pocket_min: 4            # gaps narrower than this stay solid
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

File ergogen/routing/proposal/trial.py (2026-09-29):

# Throwaway autoroute of every net but GND on a placed board, with an antenna keepout.
#   python3 trial.py <board.kicad_pcb> [passes]    (routes the board in place)
import os, sys, re, pcbnew
sys.path.insert(0, os.path.join(os.path.dirname(os.path.abspath(__file__)), '../..'))
import route
board_path = sys.argv[1]
b = pcbnew.LoadBoard(board_path)
m = b.FindFootprintByReference('MCU1')
p1 = next(p for p in m.Pads() if p.GetNumber() == '1'); bb = m.GetCourtyard(pcbnew.B_CrtYd).BBox()
x0, y0, y1 = p1.GetPosition().x + pcbnew.FromMM(1.0), bb.GetTop() - pcbnew.FromMM(3), bb.GetBottom() + pcbnew.FromMM(3)
x1 = b.GetBoardEdgesBoundingBox().GetRight() + pcbnew.FromMM(1)
z = pcbnew.ZONE(b); z.SetIsRuleArea(True); z.SetDoNotAllowTracks(True); z.SetDoNotAllowVias(True); z.SetDoNotAllowZoneFills(True)
z.SetLayerSet(pcbnew.LSET.AllCuMask()) if hasattr(pcbnew.LSET, 'AllCuMask') else None
ol = z.Outline(); ol.NewOutline()
for x, y in ((x0, y0), (x1, y0), (x1, y1), (x0, y1)): ol.Append(x, y)
b.Add(z); pcbnew.SaveBoard(board_path, b)
route.BOARD = board_path
route.SECTIONS['all'] = {'parts': r'.*', 'nets': r'^(?!GND$).+'}
route.route('all', int(sys.argv[2]) if len(sys.argv) > 2 else 30)

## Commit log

2026-09-12 Replace QMK-derived KLE with the original gist designs
    The upstream QMK ogre/ergo_* geometry was written by a maintainer in 2020
    (#9549) with no rotation; Bryan's PR-era info.json files were empty. The
    real layouts live in keyboard-layout-editor gists. Add the four relevant
    ones (proto-2-right = the 70-key board as built, starter caps, 68-key first
    PCB, OGRE 2025), a KLE deserializer/renderer, and an index of all ~150
    keyboard gists. Keep the QMK-derived file under an explicit name.
    Claude-Session: https://claude.ai/code/session_01NaUhtGSKiwH7kGUbprsAcD
2026-09-27 feat(ergogen): hand-written Ogre Ergo 70-key config
    Matches as-built PCB switch positions within 0.01 mm; verify.js checks it.
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2026-09-27 feat(ergogen): Ogre 68 staggers and wider split
    - Far and outer columns (Esc, + =, Tab, Caps Lock, Ctrl) sit 0.25U below the pinky column
    - Innermost column (~ `, } ], PgDn) sits 0.25U below the T/G/B column
    - Thumb cluster: Shift/Alt/Home block 0.25U up from Cmd, Alt/Home column another 0.25U up
    - Mirror distance 3.75U -> 4.25U to keep the 12.1 mm gap between halves
    - verify.js: right-half shift 23.81 mm, new staggered keys listed as expected differences
    - README, demo and keycap SVGs updated
    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
2026-09-27 feat(ergogen): Ogre 68 PCB with snap-apart single/split board
    - config.yaml (was ogre-ergo.yaml, renamed so ergogen.xyz loads it with footprints/)
    - 10x7 matrix nets: kept keys use as-built row/col, Home/End take row4/9 col1
    - thumb keys as wide keys turned 90deg; positions unchanged
    - outline: caps + convex thumb webs, break lines/slots/bridges from as-built board
    - footprints from as-built board: MX PCB-mount, THT diode, Pro Micro, reset, TRRS
    - 3 Pro Micros (halves + center), 3 reset switches, 2 TRRS jacks
    - build.js (injects footprints), check-pcb.js (nets, pads, KiCad DRC)
    [ogre-ergo.kicad_pcb]
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2026-09-28 feat(ergogen): live viewer that rebuilds on save
    `npm run serve` watches config.yaml and footprints/, rebuilds on save (about
    0.4 s) and refreshes the browser over SSE, so the local files stay the single
    source of truth: no push, no paste, no second copy in a web editor.
    Tabs for the keycap render, ergogen's points demo, any outline, and the PCB
    rendered by kicad-cli with a layer picker; drag to pan, wheel to zoom about the
    pointer, double click to fit. The verify and check buttons run those scripts
    and print their output. A YAML or footprint error shows in a red bar and the
    last good render stays up. Ergogen draws black on transparent, so the points
    and outline views are re-inked for a dar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
2026-09-28 feat(ergogen): pack config and footprints for the web UI
    `npm run bundle` writes output/ogre-ergo.ekb, a zip of config.yaml and
    footprints/ as they are in the working tree. The ergogen web UI opens it under
    From Local File with the footprints attached, so the PCB generates there too;
    loading a bare config.yaml gives the layout and outlines but no PCB.
    The archive is a snapshot — edits made in the web editor don't come back — so
    it is for the occasional look at the design in that UI, not for working in it.
2026-09-28 docs(ergogen): note that expand and fillet cover the whole outline
    ergogen merges a part into the accumulated outline and only then expands or
    fillets it (src/outlines.js), so the `expand: 0.5` written on web_arrows_r
    grows all four webs rather than that one hull, and has to sit on the last part
    to do so. Same reach for the `fillet: 1` in _halves.
    Comments only; board.svg and ogre.kicad_pcb hash identical after the change.
2026-09-28 docs: add AGENTS.md with the repo's working rules
    Conventional commits made as each change is made, and trunk based development
    (commit to main, no branches). Plus what an agent can't read off the tree: the
    as-built PCB is the geometric reference behind `npm run verify`, the committed
    .svg and .kicad_pcb are build output, and a rebuild's date-only diff in
    ogre-ergo.kicad_pcb doesn't belong in a commit.
    CLAUDE.md imports it with @AGENTS.md.
2026-09-28 build(ergogen): keep the generated PCB and previews out of the tree
    ogre-ergo.kicad_pcb, ogre-ergo.demo.svg and ogre-ergo.board.svg were build
    output committed alongside their source, 316 kB that `npm run build` rewrites in
    under a second. The PCB also carried a title-block date that ergogen stamps from
    the current day (templates/kicad8.js), so every rebuild dirtied the tree whether
    or not the design had changed.
    build.js now blanks that date, making a rebuild of an unchanged config
    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
    [ogre-ergo.kicad_pcb]
2026-09-28 chore(layout): drop the PNG renders, keep the SVGs
    Each PNG was a raster of the SVG beside it — 256 kB, a third of the tree, for
    files GitHub renders natively in vector form. rsvg-convert remakes any of them
    from its SVG in a second.
2026-09-28 chore(layout): keep only the as-built board's layout
    The Ogre 68 is measured against one thing: the as-built 70-key board
    (ogre-ergo.kle.json, gist "ogre - proto 2 - right"). The starter-caps dressing,
    the 2019 68-key tkl, the 2025 62-key design and the QMK-derived approximation
    were none of them inputs to it — and kle-gists.md indexes every original gist,
    so the designs stay a click away.
    The QMK-derived copy goes with qmk2kle.py that made it. Its one useful fact, the
    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
2026-09-28 docs: make the README the Ogre 68's front page
    The repo opened with "Inventory of every GitHub repo under ctrlShiftBryan",
    which was right when this was an archaeology project and wrong now that the repo
    is the new board. The front page now says what the Ogre 68 is, where it stands
    (verify green, check red on the known Pro Micro courtyard overlap, unrouted),
    how to work on it, and what the rest of the tree holds.
    The inventory and timeline move to docs/ogre-repos.md, the KLE gist history to
    layout/README.md, each still linked from the front page.
2026-09-28 refactor(ergogen): name the design values in units
    The staggers, the thumb fan and the half separation were bare numbers inside the
    zones, each explained by what the as-built board did. The as-built board was the
    starting point, not the design: the Ogre 68 is, so it should state its own
    values.
    units now carries them by name — stagger_far through stagger_extra, the thumb
    offsets, splay, spread and staggers, thumb_upper_pitch, and half_spread — with
    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
2026-09-28 feat(ergogen): gate on the design's own geometry, not the old board
    verify.js failed the build whenever a key left the position the as-built 70-key
    board gave it, with an allowlist of the changes that were permitted. That was
    right while the Ogre 68 was a diff against that board. It is the design now, so
    the allowlist had started to collect the design one entry at a time.
    It becomes compare.js (`npm run compare`): the same comparison, printed as an
    account — how many keys are still in the same place, which moved or resized,
    which went, which are new — and it never fails. It reads the right half's offset
    from half_spread, so the report follows the design rather than a constant.
    The gate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
2026-09-28 refactor(ergogen): drop the comparison against the 2019 board
    compare.js gated nothing — check covers the PCB, snapshot covers drift — and it
    got less useful the further the design went: every deliberate change moved a key
    out of its "same place" column, so a finished redesign would report that
    everything moved. Its KEYS map also hardwired today's point names to MX0-MX78,
    so renaming a column would have quietly made the report wrong.
    The Ogre 68 is designed on its own terms. The 2019 board's switch positions stay
    in git history, in layout/ogre-ergo.kle.json as the KLE design, and in the
    ogre-v1 repo.
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2026-09-28 feat(ergogen): wrap the thumb cluster tightly, with a pocket over Cmd
    The convex hulls joining the thumbs to the matrix filled a wide triangle
    under the arrow keys and Cmd. The thumb keys are now grown and shrunk back
    by thumb_web, which fills only the gaps between neighboring keys, so the
    edge follows each thumb keycap. The biggest gap left, over Cmd, is cut out
    as a pocket, like the slot on the 2019 board.
    [config.yaml]
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2026-09-28 feat(ergogen): loose diodes for the four keys beside the controllers
    5 and T (next to MCU1) and PgUp and { [ (under MCU2) take their diode as a
    separate part, starting where the built-in one was, so it can be moved clear
    of traces to the controller's pins. check-pcb follows either kind of diode.
    [config.yaml]
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2026-09-28 fix(ergogen): rewrite output in place, so the board KiCad has open never vanishes
    write() deleted output/ and wrote it back, so every build (and the viewer's on
    each save) pulled the board out from under KiCad and wiped KiCad's settings,
    history and locks. Files are now written beside themselves and renamed over the
    old ones; only stale ergogen output in points/ and outlines/ is removed, and the
    project file is written only when missing. The viewer re-reads build.js on each
    rebuild, so a running one never writes the board with stale code.
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2026-09-29 fix(ergogen): show part bodies in the viewer's PCB tab
    The Fab layers carry each footprint's body outline, and the stock power switch
    draws its body nowhere else, so it was nearly invisible. The PCB tab now plots
    F.Fab and B.Fab with the copper and silkscreen.
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2026-09-29 feat(ergogen): the controller on the board: an E73 nRF52840 module and the nice!nano v2 power section, all surface mount for JLCPCB assembly
    The nice!nano and its sockets go; each half gets an Ebyte E73-2G4M08S1C module
    (antenna end on the top edge), a BQ24075 charger/power path feeding it in
    high-voltage mode, an XC6220 LDO cut off by P0.13, a 32 kHz crystal, SWD pads
    for a TC2030 cable, a Pico-EZmate connector for a Unified Daughterboard S1 in
    the case instead of a USB-C port, a surface-mount JST PH battery connector and
    tactile reset, and two hand-soldered 3 mm LEDs on the front on a tab below
    Esc / Del. The bay beside the extra column holds it all, as a first layout to
    rearrange in KiCad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
    [config.yaml]
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2026-09-29 feat(ergogen): the controller under the keys, no bay
    The nRF52840 module lies sideways on the back below the extra column's home
    key, where that column has no bottom key, with its antenna end just inside the
    half's inner edge; the charger, LDO, crystal, passives, connectors, reset and
    SWD pads sit in the 10 mm strips between one key's socket and the next key's
    switch pins, in the inner and extra columns; the power switch is on the inner
    edge beside the charger. The bay is gone from the outline. The back-side key
    legends move into the strip past each socket, and the diodes of the three
    keys around the module and the power switch move out of their way.
    Also: JLC's LCSC number is written as a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
    [config.yaml]
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2026-09-29 feat(ergogen): the cables leave from the inner edge
    The USB and battery connectors move to the half's inner edge, under } ] and
    ~ `, opening toward it so both cables head for the middle of the case; the
    power switch goes to the bottom edge below Z, reset under % 5 and the SWD
    pads under T, each between a switch's side pins. Both halves number the
    connectors the same way now.
    [config.yaml]
2026-09-29 feat(ergogen): connectors, reset, power switch and LEDs as placed in KiCad
    The USB connector below S, the battery connector below Q with its plug
    toward the outer edge, reset below R, the power switch on the inner edge
    below ~ ` with ~ `'s diode moved under its switch, and the two LEDs one above
    the other below Esc on a narrower, taller tab. The right half mirrors it, with
    P's diode moved out of the battery connector's way. The power switch sits
    0.4 mm further in than KiCad had it, for the 0.5 mm its mounting pad needs to
    the edge.
    [config.yaml]
2026-09-29 feat(ergogen): the LEDs turned 90°, pads in a line down the tab, for bent-over LEDs
    [config.yaml]
2026-09-29 feat(ergogen): reset below ~ ` / PgUp, beside that key's diode
    [config.yaml]
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2026-09-29 feat(ergogen): a routing copy of the left half
    routing/left.kicad_pcb is the build's left board with the switches,
    sockets and diodes where the build puts them and every other part parked
    off its right edge, so the matrix can be routed with nothing else in the
    way. It is committed and the build never writes it: the start of the
    routed board as the master for copper. KiCad's session files beside it
    are ignored.
    [left.kicad_pcb]
2026-09-29 feat(ergogen): route.py autoroutes the routed board one section at a time
    A section names the parts and nets it routes; every other pad is left
    unconnected for the run and the traces already there are locked, so
    Freerouting (headless, analytics off) adds only that section. Two DSN
    fixes: the board outline goes over from KiCad's fine polygon pulled in
    0.1 mm, with the Cmd pocket grown by the edge clearance, since the
    exported chords let traces crowd the curved edge; and each hole's keepout
    goes over at its absolute spot, since Freerouting misplaces keepouts on
    the thumb keys turned off a right angle. Necked-down traces are widened
    back to the minimum. The report counts only the section's unro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
2026-09-29 feat(ergogen): the left half's matrix, autorouted
    route.py matrix: columns socket to socket, each socket to its diode and
    rows diode to diode, 0 DRC errors, 35 vias, columns mostly on the back
    and rows on the front. Home's diode (D34) is left unrouted: at the
    default spot on its turned key it sits against the board's outer edge,
    where Freerouting can't reach either pad.
    [left.kicad_pcb]
2026-09-29 feat(ergogen): route.py rip deletes a section's traces, or all of them
    Rerouting a section after its parts move means clearing it first. The
    traces go as text, matched by net, since removing items through KiCad
    10's bindings isn't safe. KiCad's local history beside the routed board
    is ignored.
2026-09-29 feat(ergogen): rip up the left half's matrix routing
    It was routed with nothing else on the board and runs where the module
    and power parts go. Parts get placed first now, then routed by section,
    most constrained first.
    [left.kicad_pcb]
2026-09-29 fix(ergogen): route.py keeps the board's keepouts in the DSN
    It dropped every structure-level keepout polygon to replace the Cmd
    pocket's coarse one, which took rule areas with it: a trial route ran
    traces through the antenna keepout. Only the outline is replaced now;
    the grown pocket keepout covers KiCad's coarse one.
2026-09-29 feat(ergogen): a placement proposal for the left half, to review
    left-placed.kicad_pcb places every part by what it connects to: the
    module's matrix pins move onto its outer-row pads (the inner row needs a
    via under the module), J1 goes under Q and J2 under A with their plugs
    entering sideways clear of the sockets, and the crystal, supply caps,
    charger and LDO chains cluster at their pins. left-trial.kicad_pcb is a
    throwaway autoroute of it: every net but GND routes, 93 vias, one DRC
    nit. The config doesn't have this placement yet; it goes in once reviewed.
    [left-placed.kicad_pcb, left-trial.kicad_pcb]
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2026-09-29 feat(ergogen): move J1 and J2 by hand in the left trial board
    J1 to (68.89, 94.6); J2 to (65.5, 114.5), turned from 90 to -90 degrees.
    Only the trial board has the moves: left-placed.kicad_pcb still has the
    old positions, and the trial's traces still end at the old pads.
    [left-trial.kicad_pcb]
